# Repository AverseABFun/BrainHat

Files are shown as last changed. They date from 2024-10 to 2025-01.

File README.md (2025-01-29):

# BrainHat
BrainHat is a project I'm working on to make a cost-effective, affordable EEG headset to better the lives of people with. The current status is an EEG headset that can read one electrode and store that onto a MicroSD card in a Raspberry Pi Zero W. The current headset contains the custom amplifier(files for which in this project), a Raspberry Pi Zero W, and my flipper zero. Code for both of the microcontrollers is in https://github.com/AverseABFun/brainhat-code.

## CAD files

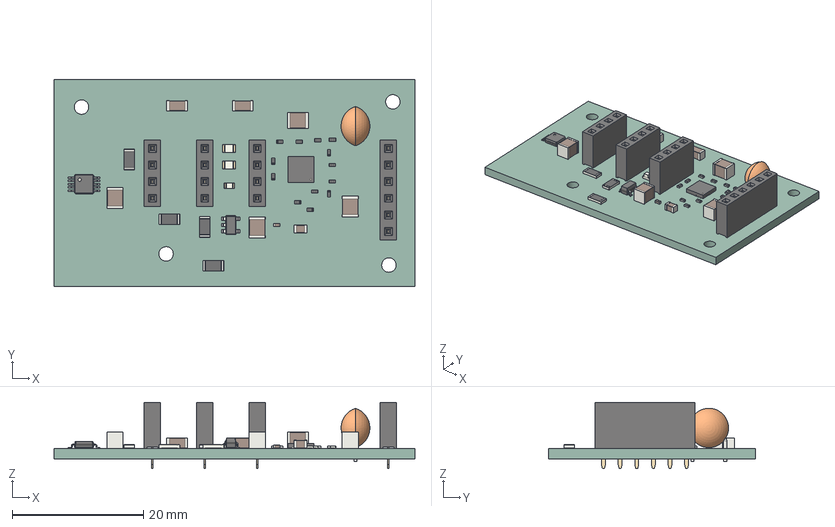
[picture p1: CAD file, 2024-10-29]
BrainHat.step
55.1 x 31.5 x 10.1 mm
LFCSP-24-1EP_4x4mm_P0.5mm_EP2.3x2.3mm
C_1206_3216Metric x 2
R_0402_1005Metric x 13
C_0402_1005Metric
R_1206_3216Metric x 4
C_1210_3225Metric x 4
C_Disc_D60mm_W44mm_P500mm
LED_0805_2012Metric x 2
PinSocket_1x06_P254mm_Vertical
C_0805_2012Metric
SOT_23_5
PinSocket_1x04_P254mm_Vertical x 3
TSSOP_10_3x3mm_P05mm
LED_0603_1608Metric
BrainHat_PCB

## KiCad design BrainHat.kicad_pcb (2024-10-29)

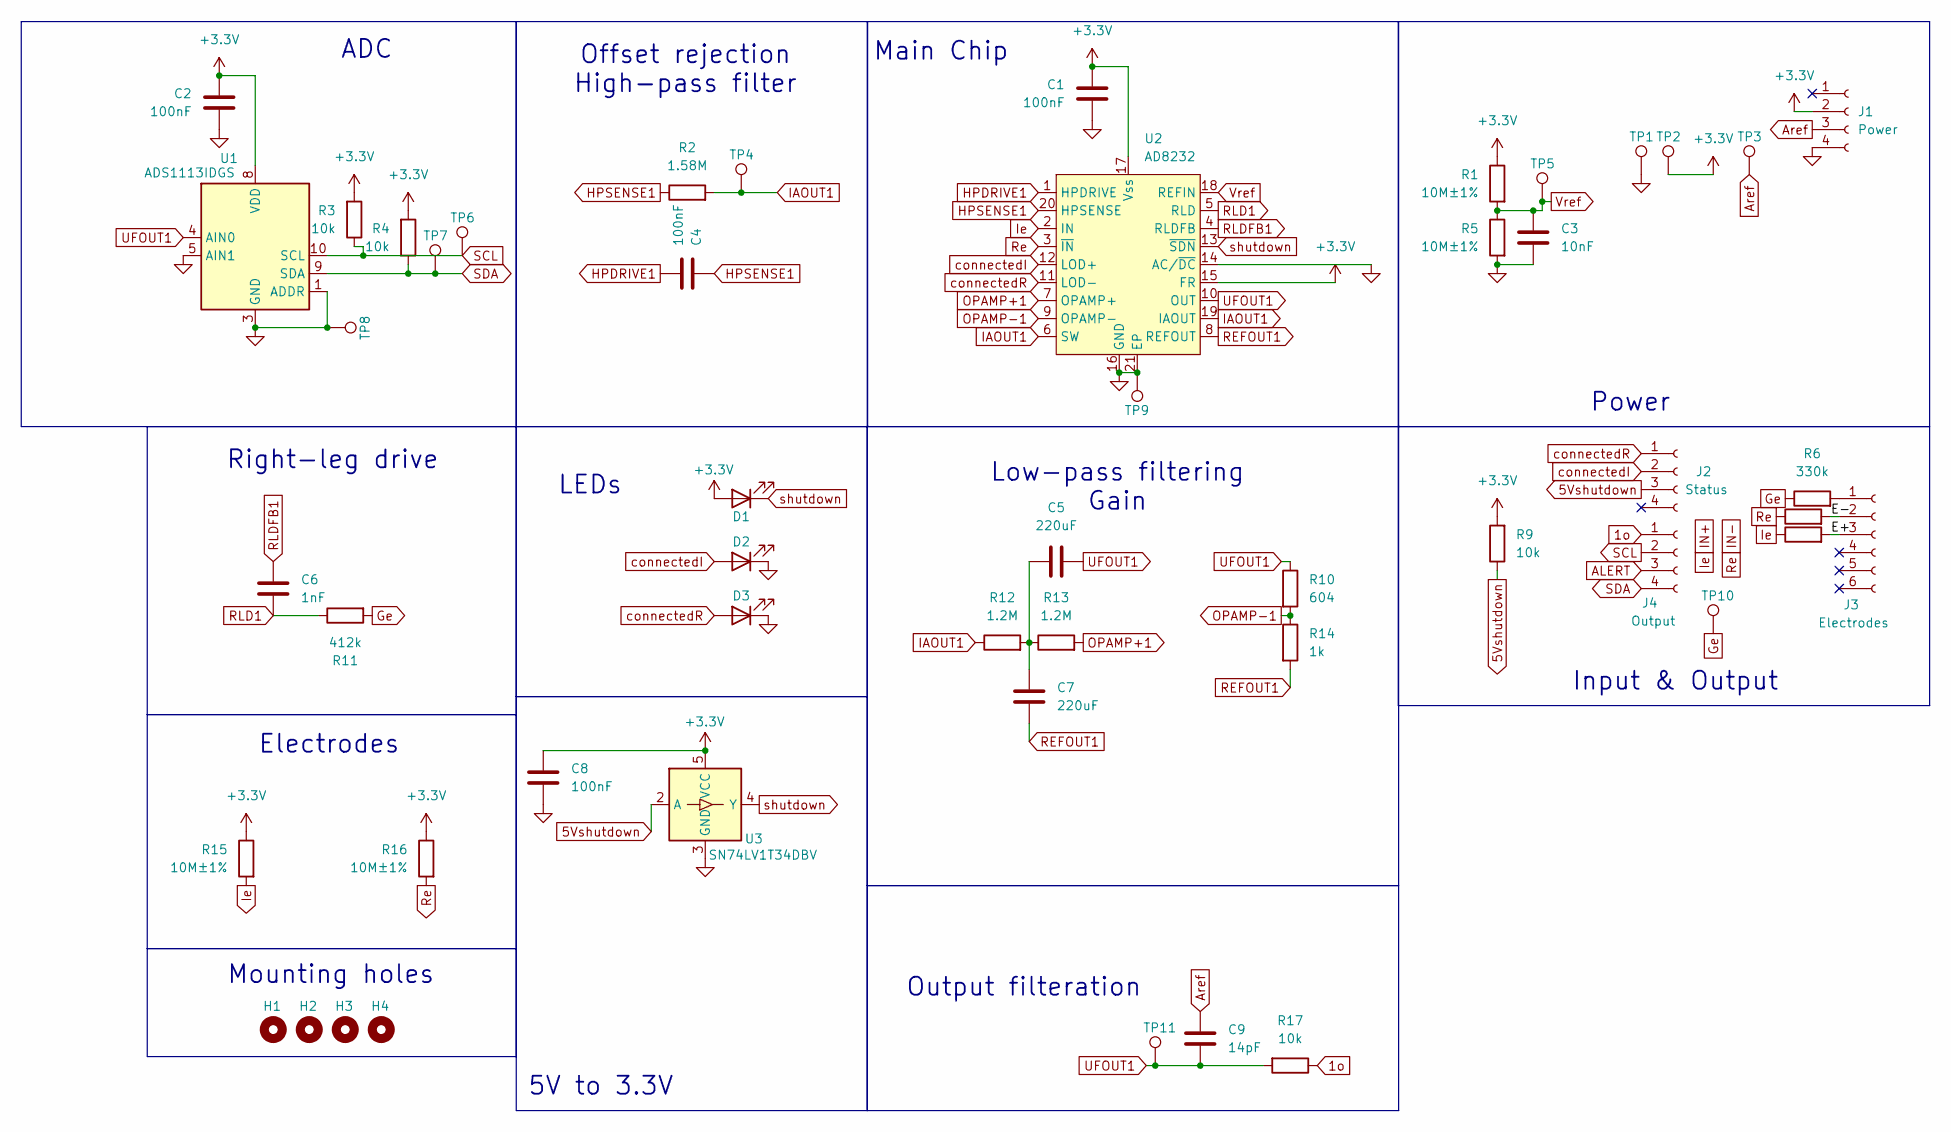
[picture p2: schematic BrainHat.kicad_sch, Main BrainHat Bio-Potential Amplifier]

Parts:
C1, C2, C4, C8: 100nF; C_1210_3225Metric; LCSC Part # C569766
C3: 10nF; C_0805_2012Metric; LCSC Part # C5448895
C5, C7: 220uF; C_1206_3216Metric; LCSC Part # C412252
C6: 1nF; C_Disc_D6.0mm_W4.4mm_P5.00mm; LCSC Part # C2887268
C9: 14pF; C_0402_1005Metric; LCSC Part # C3037644
D1: XL-1608UBC-04; LED_0603_1608Metric; LCSC Part # C965807
D2, D3: XL-2012UWC; LED_0805_2012Metric; LCSC Part # C965818
H1, H2, H3, H4: MountingHole; MountingHole_2.2mm_M2
J1: Power; PinSocket_1x04_P2.54mm_Vertical; LCSC Part # C5116530
J2: Status; PinSocket_1x04_P2.54mm_Vertical; LCSC Part # C5116530
J3: Electrodes; PinHeader_1x06_P2.54mm_Vertical; LCSC Part # C7509518
J4: Output; PinSocket_1x04_P2.54mm_Vertical; LCSC Part # C5116530
R1, R5, R15, R16: 10M±1%; R_0402_1005Metric; LCSC Part # C2933065
R2: 1.58M; R_0402_1005Metric; LCSC Part # C368345
R3, R4, R9, R17: 10k; R_1206_3216Metric; LCSC Part # C17902
R6, R7, R8: 330k; R_0402_1005Metric; LCSC Part # C3017599
R10: 604; R_0402_1005Metric; LCSC Part # C2998094
R11: 412k; R_0402_1005Metric; LCSC Part # C5126037
R12, R13: 1.2M; R_0402_1005Metric; LCSC Part # C43675
R14: 1k; R_0402_1005Metric; LCSC Part # C2906899
TP1, TP2, TP3, TP4, TP5, TP6, TP7, TP8, TP9, TP10, TP11: TestPoint; TestPoint_Pad_D1.5mm
U1: ADS1113IDGS; TSSOP-10_3x3mm_P0.5mm
U2: AD8232; LFCSP-20-1EP_4x4mm_P0.5mm_EP2.5x2.5mm; LCSC Part # C43216
U3: SN74LV1T34DBV; SOT-23-5; LCSC Part # C100024

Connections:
1o: J4.1, R17.1
5Vshutdown: J2.3, R9.1, U3.2 (A)
+3.3V: C1.1, C2.1, C8.1, D1.2 (A), J1.2, R1.1, R3.2, R4.2, R9.2, R15.1, R16.1, TP2.1, U1.8 (VDD), U2.15 (FR), U2.17 (Vss), U3.5 (VCC)
/E+: J3.3, R8.2
/E-: J3.2, R7.2
ALERT: J4.3
Aref: C9.1, J1.3, TP3.1
GND: C1.2, C2.2, C3.2, C8.2, D2.1 (K), D3.1 (K), J1.4, R5.2, TP1.1, TP8.1, TP9.1, U1.1 (ADDR), U1.3 (GND), U1.5 (AIN1), U2.14 (AC/~DC), U2.16 (GND), U2.21 (EP), U3.3 (GND)
Ge: R6.1, R11.2, TP10.1
HPDRIVE1: C4.2, U2.1 (HPDRIVE)
HPSENSE1: C4.1, R2.1, U2.20 (HPSENSE)
IAOUT1: R2.2, R12.1, TP4.1, U2.6 (SW), U2.19 (IAOUT)
IN+: R8.1, R15.2, U2.2 (IN)
IN-: R7.1, R16.2, U2.3 (~IN)
unnamed: C5.1, C7.1, R12.2, R13.1
unnamed: J3.1, R6.2
OPAMP+1: R13.2, U2.7 (OPAMP+)
OPAMP-1: R10.2, R14.1, U2.9 (OPAMP-)
REFOUT1: C7.2, R14.2, U2.8 (REFOUT)
RLD1: C6.2, R11.1, U2.5 (RLD)
RLDFB1: C6.1, U2.4 (RLDFB)
SCL: J4.2, R3.1, TP6.1, U1.10 (SCL)
SDA: J4.4, R4.1, TP7.1, U1.9 (SDA)
UFOUT1: C5.2, C9.2, R10.1, R17.2, TP11.1, U1.4 (AIN0), U2.10 (OUT)
Vref: C3.1, R1.2, R5.1, TP5.1, U2.18 (REFIN)
connectedI: D2.2 (A), J2.2, U2.12 (LOD+)
connectedR: D3.2 (A), J2.1, U2.11 (LOD-)
shutdown: D1.1 (K), U2.13 (~SDN), U3.4 (Y)

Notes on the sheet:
5V to 3.3V
Low-pass filtering Gain
Mounting holes
Power
Output filteration
ADC
Right-leg drive
LEDs
Input & Output
Main Chip
Offset rejection High-pass filter
Electrodes

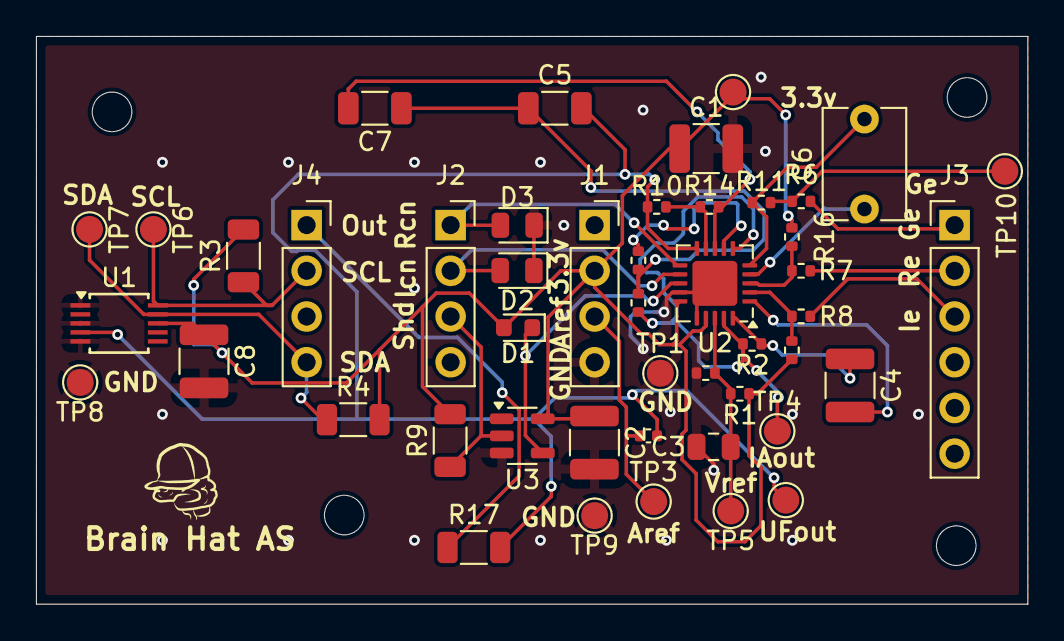
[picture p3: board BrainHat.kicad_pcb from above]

Board: 2 copper layers, 55.1 x 31.5 mm, 51 parts (0 on the bottom side), 27 nets.

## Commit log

2024-08-09 Organized and added mux
    [EEG amp.kicad_sch]
2024-08-09 added lock files to gitignore and changed the mux a bit
    [EEG amp.kicad_sch]
2024-08-09 Organization and status LEDs
    [EEG amp.kicad_sch]
2024-08-10 Organized better and got some tips from from a professional PCB designer :3
    [EEG amp.kicad_sch]
2024-08-10 slightly rearranged things
    [EEG amp.kicad_sch]
2024-08-10 Started work on the PCB
    [EEG amp.kicad_pcb]
2024-08-10 Designed PCB and apparently did something to the schematic
    [EEG amp.kicad_pcb, EEG amp.kicad_sch]
2024-08-10 Changed gitignore, reorganized schematic a bit, connected EP to ground, and updated the symbol
    [EEG amp.kicad_pcb, EEG amp.kicad_sch]
2024-09-01 Messed with schematic and(I think) finished PCB
    [EEG amp.kicad_pcb, EEG amp.kicad_sch]
2024-09-01 Ran DRC and changed ground plane
    [EEG amp.kicad_pcb]
2024-09-01 Exported various files for OnBoard
    [EEG amp.kicad_sch]
2024-09-03 adjusted many things, including, apparently, the footprint for one of the resistors
    [EEG amp.kicad_pcb, EEG amp.kicad_sch]
2024-09-15 Renamed everything
    [BrainHat.kicad_pcb, BrainHat.kicad_sch]
2024-09-27 Started work on version 2
    [BrainHat.kicad_sch]
2024-10-01 Redid PCB again
    [BrainHat.kicad_pcb, BrainHat.kicad_sch]
2024-10-13 Made a variety of changes
    [BrainHat.kicad_pcb, BrainHat.kicad_sch]
2024-10-29 made many a change
    [BrainHat.kicad_pcb, BrainHat.kicad_sch, BrainHat.step]
